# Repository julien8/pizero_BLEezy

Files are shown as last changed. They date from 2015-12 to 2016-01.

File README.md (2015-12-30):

# Bleezy: Raspberry Pi Zero BLE Module #

Using the nRF52188 a very interesting BLE solution for the Raspberry Pi is realized. The Raspberry Pi allows you to use OpenOCD to program the nRF chips ARM M0 core. This opens up potentioal for a variety of applications where Bluetooth can be used to monitor and control the state of the Raspberry Pi. 

*This project is licensed under the CERN OHL v1.2*

### Features ###

-nRF52188
-Coincell battery

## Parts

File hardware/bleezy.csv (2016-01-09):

Reference | Value | Footprint | Datasheet | Mouser Part No.
P3 | Raspberry_Pi_+_Conn | w_conn_strip:vasch_strip_20x2 |  | 517-929975-01-20
IC1 | NRF51822 | w_smd_qfn:pvqfn-n48 |  | 949-NRF51822-QFAA-R7
P6 | TST | openfet-footprint:Ant_24ghz_small
C6 | 47nf | w_smd_cap:c_0402 |  | 81-GRM15B11A473KA01D
C5 | 100nf | w_smd_cap:c_0402 |  | 81-GRM155R71C104KA88
P1 | Analog Header | w_pin_strip:pin_strip_8
Y2 | 16Mhz | w_crystal:crystal_fa128 |  | 581-CX2520DB16DGEJCC
Y1 | 32Khz | w_crystal:crystal_tc-38_horiz |  | 815-AB38T-32.768KHZ
C4 | 13pf | w_smd_cap:c_0402 |  | 81-GRM1555C1H130JA1D
C7 | 13pf | w_smd_cap:c_0402 |  | 81-GRM1555C1H130JA1D
C9 | 8pf | w_smd_cap:c_0402 |  | 81-GRM1555C1H8R0DA1D
C10 | 8pf | w_smd_cap:c_0402 |  | 81-GRM1555C1H8R0DA1D
P2 | Digital Con 2 | w_pin_strip:pin_strip_8
P5 | Power Con | w_pin_strip:pin_strip_4
U1 | LD3985M33R | TO_SOT_Packages_SMD:SOT-23-5 |  | 511-LD3985M33R
C1 | 2.2uf | w_smd_cap:c_0402 |  | 581-04026D225KAT2A
C2 | 1.0uf | w_smd_cap:c_0603 |  | 581-06036D105K
BT1 | Coin Cell | openfet-footprint:keystone_3003 |  | 534-3003
C3 | 10uf | w_smd_cap:c_tant_B |  | 581-TAJB106K006R
D1 | D_Schottky_x2_KCom_KAA | w_smd_trans:sot23 |  | 726-BAS7005E6327XT
R1 | 10k | w_smd_resistors:r_0402 |  | 754-RR0510P-103D
R2 | 10k | w_smd_resistors:r_0402 |  | 754-RR0510P-103D
D2 | Blue 470nm | w_smd_leds:Led_0603 |  | 859-LTST-C191TBKT-5A
R3 | 110 | w_smd_resistors:r_0402 |  | 754-RR0510P-111D
C8 | 2.2nf | w_smd_cap:c_0402 |  | GRM155R71H222KA01D
C11 | 2.2pf | w_smd_cap:c_0402 |  | 81-GRM1555C1H2R2BA1D
L3 | 3.3nH | w_smd_inductors:inductor_smd_0402
C12 | 1pf | w_smd_cap:c_0402 |  | GRM1555C1H1R0CA01D
C13 | 1.5pf | w_smd_cap:c_0402 |  | GRM1555C1H1R5BA01D
JP1 | JUMPER | w_smd_cap:c_0603
L1 | 4.7nH | w_smd_inductors:inductor_smd_0402 |  | 81-LQW15AN4N7C00D
L2 | 10nH | w_smd_inductors:inductor_smd_0402 |  | 994-0402HP-10NXJLU
C14 | 100nf | w_smd_cap:c_0402 |  | 81-GRM155R71C104KA88
C15 | 100nf | w_smd_cap:c_0402 |  | 81-GRM155R71C104KA88
L5 | 10uH | w_smd_inductors:inductor_smd_0603 |  | 963-LK1608100K-T
L6 | 15nH | w_smd_inductors:inductor_smd_0402 |  | 81-LQW15AN15NJ00D
C16 | 1.0uf | w_smd_cap:c_0402 |  | 81-GRM155R61A105KE15
Q1 | BSS138 | w_smd_trans:sot23 |  | 621-DMG2305UX-13
U5 | DMMT5401 | w_smd_trans:sot23-6 |  | 621-DMMT5401-7-F
R12 | 47k | w_smd_resistors:r_0402 |  | 667-ERJ-2RKF4702X
R11 | 10k | w_smd_resistors:r_0402 |  | 71-CRCW0402-10K-E3

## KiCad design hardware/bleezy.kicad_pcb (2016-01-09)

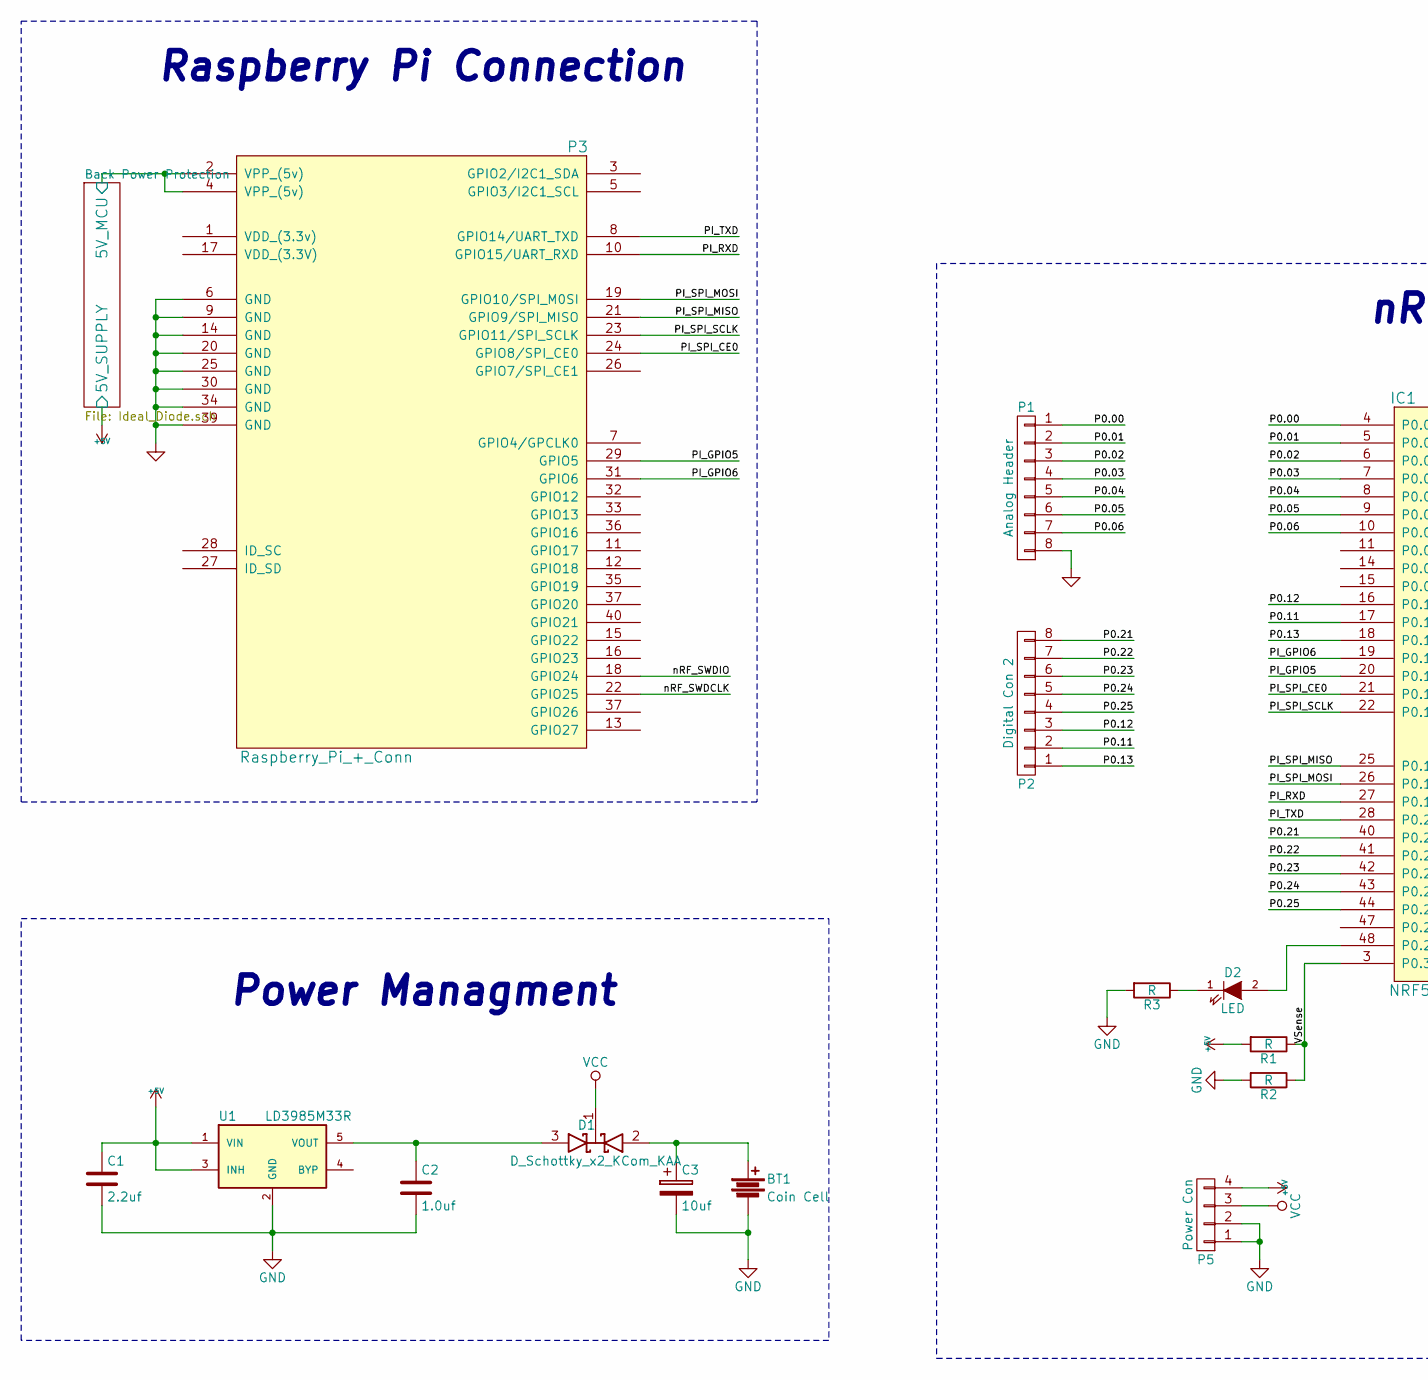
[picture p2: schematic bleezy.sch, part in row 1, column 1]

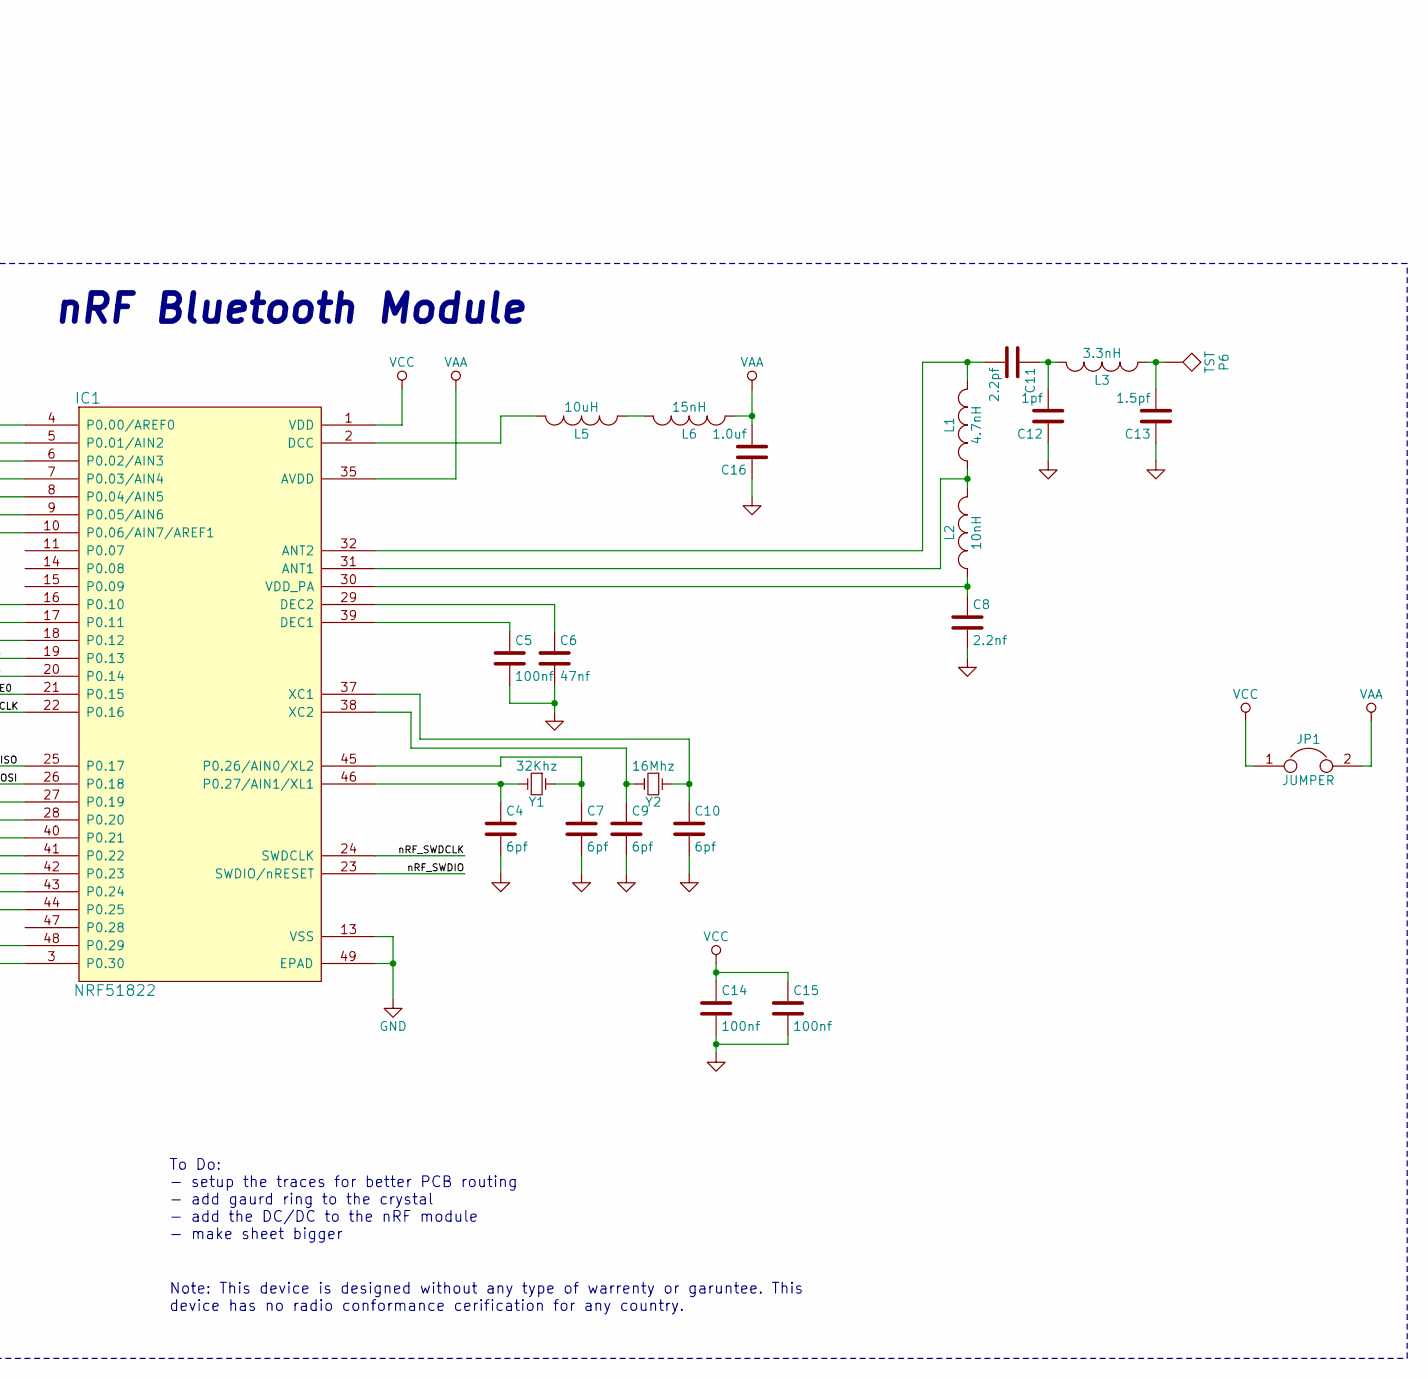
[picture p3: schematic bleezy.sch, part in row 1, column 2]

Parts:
BT1: Coin Cell; keystone_3003
C1: 2.2uf; c_0402
C2: 1.0uf; c_0603
C3: 10uf; c_tant_B
C4, C7, C9, C10: 6pf; c_0402
C5, C14, C15: 100nf; c_0402
C6: 47nf; c_0402
C8: 2.2nf; c_0402
C11: 2.2pf; c_0402
C12: 1pf; c_0402
C13: 1.5pf; c_0402
C16: 1.0uf; c_0402
D1: D_Schottky_x2_KCom_KAA; sot23; Mouser Part No. 726-BAS7005E6327XT
D2: LED; Led_0603
IC1: NRF51822; pvqfn-n48
JP1: JUMPER; c_0603
L1: 4.7nH; inductor_smd_0402
L2: 10nH; inductor_smd_0402
L3: 3.3nH; inductor_smd_0402
L5: 10uH; inductor_smd_0603
L6: 15nH; inductor_smd_0402
P1: Analog Header; pin_strip_8
P2: Digital Con 2; pin_strip_8
P3: Raspberry_Pi_+_Conn; vasch_strip_20x2; Mouser Part No. 517-30340-6002
P5: Power Con; pin_strip_4
P6: TST; Ant_24ghz_small
R1, R2, R3: R; r_0402
U1: LD3985M33R; SOT-23-5
Y1: 32Khz; crystal_tc-38_horiz
Y2: 16Mhz; crystal_fa128

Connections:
+5V: C1.1, P5.4, R1.2, U1.1 (VIN), U1.3 (INH); also elsewhere on the board
/Back Power Protection/5V_MCU: P3.2 (VPP_(5v)), P3.4 (VPP_(5v)); also elsewhere on the board
/P0.00: IC1.4 (P0.00/AREF0), P1.1
/P0.01: IC1.5 (P0.01/AIN2), P1.2
/P0.02: IC1.6 (P0.02/AIN3), P1.3
/P0.03: IC1.7 (P0.03/AIN4), P1.4
/P0.04: IC1.8 (P0.04/AIN5), P1.5
/P0.05: IC1.9 (P0.05/AIN6), P1.6
/P0.06: IC1.10 (P0.06/AIN7/AREF1), P1.7
/P0.11: IC1.17 (P0.11), P2.2
/P0.12: IC1.16 (P0.10), P2.3
/P0.13: IC1.18 (P0.12), P2.1
/P0.21: IC1.40 (P0.21), P2.8
/P0.22: IC1.41 (P0.22), P2.7
/P0.23: IC1.42 (P0.23), P2.6
/P0.24: IC1.43 (P0.24), P2.5
/P0.25: IC1.44 (P0.25), P2.4
/PI_GPIO5: IC1.20 (P0.14), P3.29 (GPIO5)
/PI_GPIO6: IC1.19 (P0.13), P3.31 (GPIO6)
/PI_RXD: IC1.27 (P0.19), P3.10 (GPIO15/UART_RXD)
/PI_SPI_CE0: IC1.21 (P0.15), P3.24 (GPIO8/SPI_CE0)
/PI_SPI_MISO: IC1.25 (P0.17), P3.21 (GPIO9/SPI_MISO)
/PI_SPI_MOSI: IC1.26 (P0.18), P3.19 (GPIO10/SPI_M0SI)
/PI_SPI_SCLK: IC1.22 (P0.16), P3.23 (GPIO11/SPI_SCLK)
/PI_TXD: IC1.28 (P0.20), P3.8 (GPIO14/UART_TXD)
/VSense: IC1.3 (P0.30), R1.1, R2.1
/nRF_SWDCLK: IC1.24 (SWDCLK), P3.22 (GPIO25)
/nRF_SWDIO: IC1.23 (SWDIO/nRESET), P3.18 (GPIO24)
AVDD: C16.2, IC1.35 (AVDD), IC1.36 (AVDD), JP1.2, L6.1
GND: BT1.2, C1.2, C2.2, C3.2, C4.2, C5.2, C6.2, C7.2, C8.2, C9.2, C10.2, C12.1, C13.1, C14.2, C15.2, C16.1, IC1.13 (VSS), IC1.33 (VSS), IC1.34 (VSS), IC1.49 (EPAD), P1.8, P3.6 (GND), P3.9 (GND), P3.14 (GND), P3.20 (GND), P3.25 (GND), P3.30 (GND), P3.34 (GND), P3.39 (GND), P5.1, P5.2, R2.2, R3.2, U1.2 (GND); also elsewhere on the board
unnamed: BT1.1, C3.1, D1.2 (A)
unnamed: C2.1, D1.3 (A), U1.5 (VOUT)
unnamed: C4.1, IC1.46 (P0.27/AIN1/XL1), Y1.2
unnamed: C5.1, IC1.39 (DEC1)
unnamed: C6.1, IC1.29 (DEC2)
unnamed: C7.1, IC1.45 (P0.26/AIN0/XL2), Y1.1
unnamed: C8.1, IC1.30 (VDD_PA), L2.1
unnamed: C9.1, IC1.38 (XC2), Y2.2
unnamed: C10.1, IC1.37 (XC1), Y2.1
unnamed: C11.1, C12.2, L3.2
unnamed: C11.2, IC1.32 (ANT2), L1.2
unnamed: C13.2, L3.1, P6.1
unnamed: D2.1 (K), R3.1
unnamed: D2.2 (A), IC1.48 (P0.29)
unnamed: IC1.2 (DCC), L5.2
unnamed: IC1.31 (ANT1), L1.1, L2.2
unnamed: L5.1, L6.2
VCC: C14.1, C15.1, D1.1 (K), IC1.1 (VDD), IC1.12 (VDD), JP1.1, P5.3

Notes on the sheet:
Raspberry Pi Connection
nRF Bluetooth Module
Power Managment
Note: This device is designed without any type of warrenty or garuntee. This device has no radio conformance cerification for any country.
To Do: - setup the traces for better PCB routing - add gaurd ring to the crystal - add the DC/DC to the nRF module - make sheet bigger

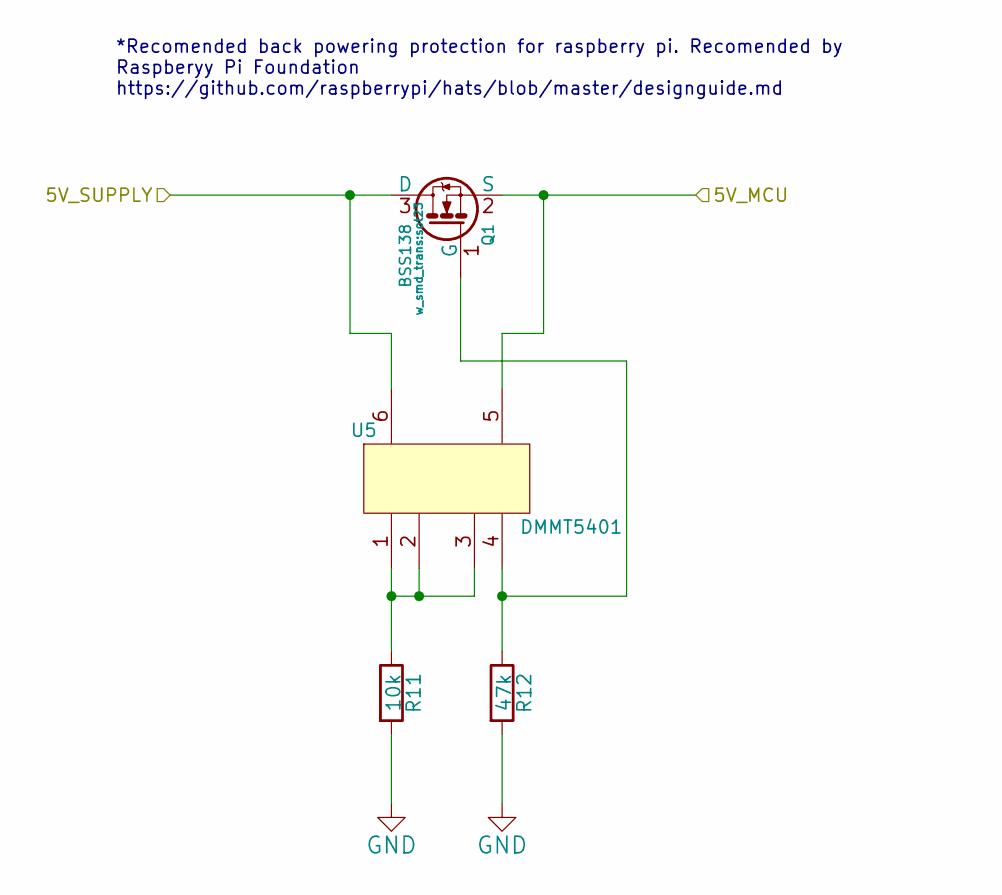
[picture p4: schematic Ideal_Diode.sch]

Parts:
Q1: BSS138; sot23; Mouser Part No. 621-DMG2305UX-13
R11: 10k; r_0402; Mouser Part No. 71-CRCW0402-10K-E3
R12: 47k; r_0402; Mouser Part No. 667-ERJ-2RKF4702X
U5: DMMT5401; sot23-6; Mouser Part No. 621-DMMT5401-7-F

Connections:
+5V: Q1.3 (D), U5.6; also elsewhere on the board
/Back Power Protection/5V_MCU: Q1.2 (S), U5.5; also elsewhere on the board
GND: R11.2, R12.2; also elsewhere on the board
unnamed: Q1.1 (G), R12.1, U5.4
unnamed: R11.1, U5.1, U5.2, U5.3

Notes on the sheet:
*Recomended back powering protection for raspberry pi. Recomended by Raspberyy Pi Foundation https://github.com/raspberrypi/hats/blob/master/designguide.md

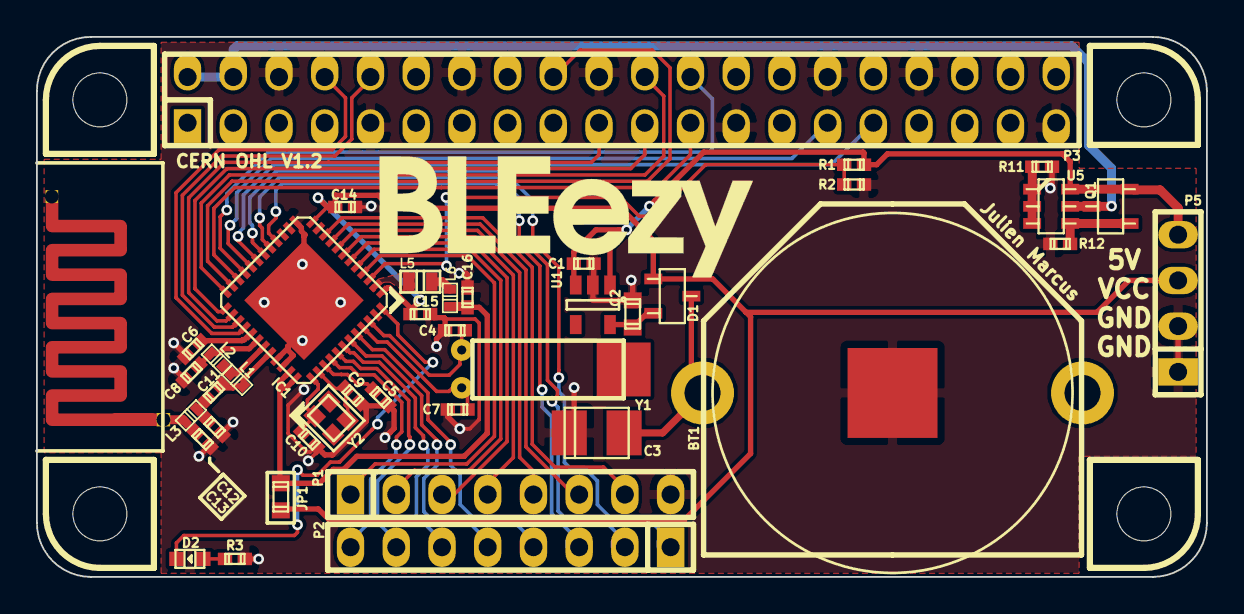
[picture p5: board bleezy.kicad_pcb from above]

Board: 2 copper layers, 65.0 x 30.0 mm, 41 parts (0 on the bottom side), 50 nets.

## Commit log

2015-12-24 fixed a library link issue
    [Ideal_Diode.sch, pihat_template.sch]
2015-12-30 Initial commit of bleezy
    [bleezy.sch]
2015-12-31 added LED and vsense net
    [bleezy.sch]
2015-12-31 placed major components
    [bleezy.kicad_pcb]
2015-12-31 major group changes
    [Ideal_Diode.sch, pihat_template.kicad_pcb, pihat_template.sch]
2015-12-31 cleaned up schematic
    [bleezy.sch]
2015-12-31 removed monolithic balun
    [bleezy.sch]
2015-12-31 redid basic layout, some routing
    [Ideal_Diode.sch, bleezy.kicad_pcb, bleezy.sch]
2016-01-06 finished routing
    [Ideal_Diode.sch, bleezy.kicad_pcb, bleezy.sch]
2016-01-07 added some to do
    [bleezy.sch]
2016-01-07 added DC/DC, changed some pinouts
    [bleezy.sch]
2016-01-07 rerouted with new pinout and bat on top
    [bleezy.kicad_pcb]
2016-01-07 updates after re-routing
    [Ideal_Diode.sch]
2016-01-07 Updated PCB routing
    Mostly aesthetic changes...
    Beefed up a few power-lines.
    Added guard-rings around the crystals
    Made the B.Cu ground-plane contigous (although it has a narrow passage)
    Removed a lot of unncessary vias
    [bleezy.kicad_pcb]
2016-01-09 changed some silk labels
    [bleezy.kicad_pcb]
2016-01-09 inital commit of BOM complete, untested
    [bleezy.csv]
2016-01-09 added part numbers to component feilds
    [bleezy.sch]

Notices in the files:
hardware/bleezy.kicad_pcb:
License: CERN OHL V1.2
